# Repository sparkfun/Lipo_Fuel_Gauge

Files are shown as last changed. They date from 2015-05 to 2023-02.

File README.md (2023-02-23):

SparkFun LiPo Fuel Gauge - MAX17043
========================================

SparkFun LiPo Fuel Gauge (https://www.sparkfun.com/products/20680)

[*SparkFun LiPo Fuel Gauge (TOL-20680)*](https://www.sparkfun.com/products/20680)

LiPo batteries are a great way to power your projects. They're small, lightweight, and pack a good punch for their size. Unfortunately, even the best batteries eventually run low on power, and when they do it's often unexpected (and at the worst time). Don't be caught by surprise next time your board suddenly powers down! 

The SparkFun LiPo Fuel Gauge connects your battery to your project and uses a sophisticated algorithm to detect the relative state of charge and direct A/D measurement of battery voltage. In other words, it tells your microcontroller how much 'fuel' is left in the tank. The LiPo Fuel Gauge communicates with your project over I<sup>2</sup>C and an alert pin also tells you when the charge has dropped below a certain percentage.

Repository Contents
-------------------

* **/Firmware** - Example C code 
* **/Hardware** - Eagle design files (.brd, .sch)
* **/Production** - Production panel files (.brd)

Documentation
--------------
* **[Particle Photon Library](https://github.com/sparkfun/SparkFun_MAX17043_Particle_Library)** - Particle Library for the MAX17043 that is used in the [SparkFun Photon Battery Shield](https://www.sparkfun.com/products/13626).
* **[Arduino Project Example](https://learn.sparkfun.com/tutorials/wireless-joystick-hookup-guide#MAX17043)** - Arduino project example that uses the MAX17043 in the [Wireless Joystick Kit](https://www.sparkfun.com/products/14051).
* **[SparkFun Arduino Library](https://github.com/sparkfun/SparkFun_MAX1704x_Fuel_Gauge_Arduino_Library)** - SparkFun Arduino library
* **[Arduino Library](https://github.com/porrey/max1704x)** - Arduino library from user "porrey." This is another Arduino library that is available. 
* **SparkFun Fritzing repo** - Fritzing diagrams for SparkFun products.
  * **[TOL-20680](https://github.com/sparkfun/Fritzing_Parts/blob/main/products/20680_sfe_lipo_fuel_gauge_MAX17043_MAX1704X.fzpz)**
  * **[TOL-10617](https://github.com/sparkfun/Fritzing_Parts/blob/main/products/10617_sfe_lipo_fuel_gauge.fzpz)**
* **[SparkFun 3D Model repo](https://github.com/sparkfun/3D_Models)** - 3D models of SparkFun products.
* **[Hookup Guide](https://learn.sparkfun.com/tutorials/2946)** - Basic hookup guide for the MAX17043 and MAX17048.

Product Versions
----------------
* [TOL-20680](https://www.sparkfun.com/products/20680) - v1.2
* [TOL-10617](https://www.sparkfun.com/products/10617) - Initial Release, v1.1

License Information
-------------------
This product is _**open source**_! 

The **hardware** is released under [Creative Commons ShareAlike 4.0 International](https://creativecommons.org/licenses/by-sa/4.0/).

The **code** is beerware; if you see me (or any other SparkFun employee) at the local, and you've found our code helpful, please buy us a round!

Please use, reuse, and modify these files as you see fit. Please maintain attribution to SparkFun Electronics and release anything derivative under the same license.

Distributed as-is; no warranty is given.

- Your friends at SparkFun.

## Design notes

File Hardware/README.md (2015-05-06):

SparkFun <PRODUCT NAME> Design Files
=====================================

The .sch and .brd files hare are Eagle CAD schematic and PCB design files from SparkFun Electronics.
A freeware version of Eagle can be found [here](http://www.cadsoftusa.com/download-eagle/freeware/). 

License
---------
This product is open source! 
The hardware is released under [Creative Commons ShareAlike 4.0 International](https://creativecommons.org/licenses/by-sa/4.0/).

Please use, reuse, and modify these files as you see fit. Please maintain attribution to SparkFun Electronics and release anything derivative under the same license.

Distributed as-is; no warranty is given.

- Your friends at SparkFun.

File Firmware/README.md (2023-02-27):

SparkFun Lipo Fuel Gauge Firmware
===================================

* **Arduino** - Arduino examples.
* **SparkFunLipoFuelGauge** - C examples. V_1.0

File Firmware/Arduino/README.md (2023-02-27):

SparkFun Lipo Fuel Gauge Firmware
===================================

Documentation
--------------

* **[Installing an Arduino Library Guide](https://learn.sparkfun.com/tutorials/installing-an-arduino-library)** - Basic information on how to install an Arduino library.
* **[SparkFun Qwiic OLED Arduino Library](https://github.com/sparkfun/SparkFun_Qwiic_OLED_Arduino_Library)**
* **[SparkFun MAX1704X Fuel Gauge Arduino Library](https://github.com/sparkfun/SparkFun_MAX1704x_Fuel_Gauge_Arduino_Library)**

_Note: The following examples combine code from both the Qwiic OLED and the LiPo Fuel Gauge Arduino Library. Note that there are two SparkFun Arduino Libraries for the Qwiic Micro OLED that can be used._

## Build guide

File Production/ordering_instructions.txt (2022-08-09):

panel size, 99x211mm
PCB thickness, 1.6mm
number of layers, 2
soldermask color, Red
silkscreen color, White
oz copper, 1oz
finish, HASL lead free
stencils, top
pcs per panel, 64
min trace width, 0.2032mm / 0.0080in
min drill size, 0.3810mm / 0.0150in

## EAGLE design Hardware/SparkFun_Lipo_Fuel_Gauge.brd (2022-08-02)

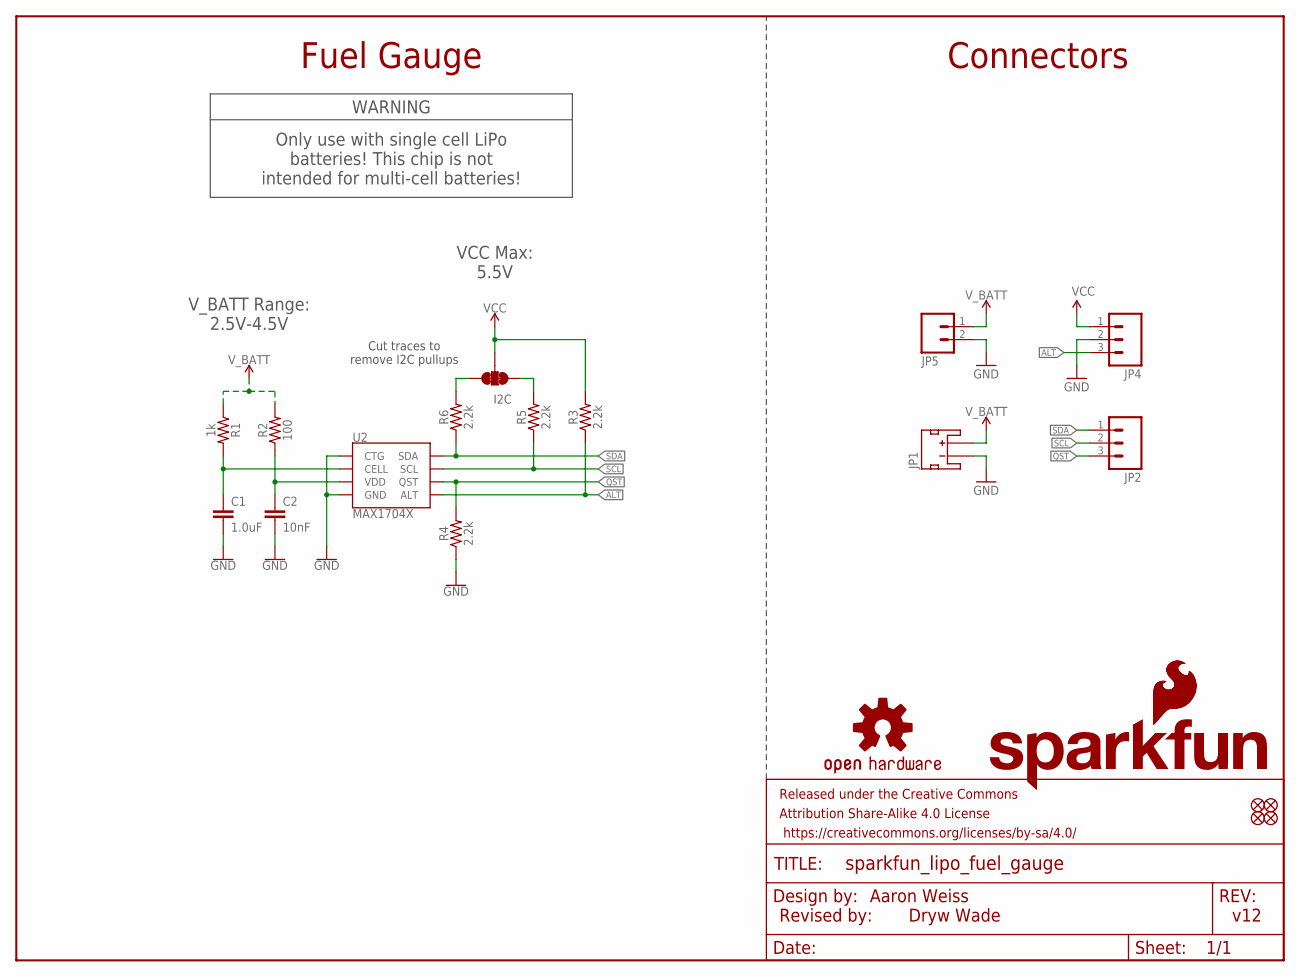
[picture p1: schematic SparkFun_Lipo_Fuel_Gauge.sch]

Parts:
C1: 1.0uF; 0402-TIGHT
C2: 10nF; 0402-TIGHT
FRAME1: FRAME-LETTER; CREATIVE_COMMONS
I2C: JUMPER-SMT_3_2-NC_TRACE_SILK; SMT-JUMPER_3_2-NC_TRACE_SILK
JP1: input; JST-2-SMD
JP2, JP4: CONN_031X03_NO_SILK; 1X03_NO_SILK
JP3: SFE_LOGO_FLAME.1_INCH; SFE_LOGO_FLAME_.1
JP5: CONN_021X02_NO_SILK; 1X02_NO_SILK
JP6, JP7, JP8, JP9: FIDUCIALUFIDUCIAL; FIDUCIAL-MICRO
LOGO1: SFE_LOGO_NAME_FLAMEBLANK; BLANK
R1: 1k; 0402-TIGHT
R2: 100; 0402-TIGHT
R3, R4, R5, R6: 2.2k; 0402-TIGHT
U2: MAX1704X; TDFN-8
U$1: OSHW-LOGOS; OSHW-LOGO-S

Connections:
ALT: JP4.3, R3.1, U2.5 (ALT)
GND: C1.2, C2.2, JP1.1 (-), JP4.2, JP5.2, R4.1, U2.1 (CTG), U2.4 (GND), U2.EP (GND)
unnamed: I2C.3, R6.2
unnamed: C1.1, R1.2, U2.2 (CELL)
unnamed: I2C.1, R5.2
QST: JP2.3, R4.2, U2.6 (QST)
SCL: JP2.2, R5.1, U2.7 (SCL)
SDA: JP2.1, R6.1, U2.8 (SDA)
VCC: I2C.2, JP4.1, R3.2
VDD: C2.1, R2.1, U2.3 (VDD)
V_BATT: JP1.2 (+), JP5.1, R1.1, R2.2

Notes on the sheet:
v12
Aaron Weiss
Revised by:
Dryw Wade
Connectors
Fuel Gauge
WARNING
Only use with single cell LiPo batteries! This chip is not intended for multi-cell batteries!
V_BATT Range: 2.5V-4.5V
VCC Max: 5.5V
Cut traces to remove I2C pullups

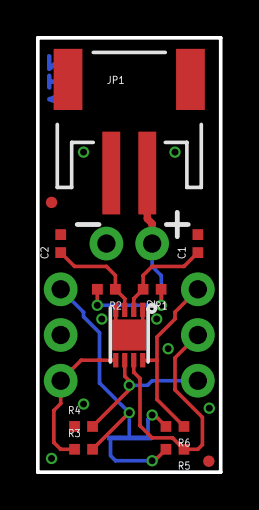
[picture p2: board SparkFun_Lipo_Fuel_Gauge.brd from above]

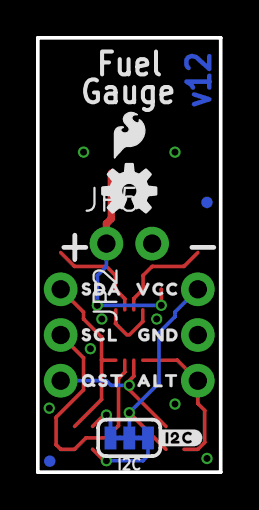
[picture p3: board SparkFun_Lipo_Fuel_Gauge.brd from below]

Board: 2 copper layers, 10.2 x 24.1 mm, 29 parts (15 on the bottom side), 11 nets.

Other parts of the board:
U$2: SDA0
U$3: SCL0
U$4: QST0
U$5: VCC0
U$6: GND0
U$7: ALT0
U$8: #I2C#0

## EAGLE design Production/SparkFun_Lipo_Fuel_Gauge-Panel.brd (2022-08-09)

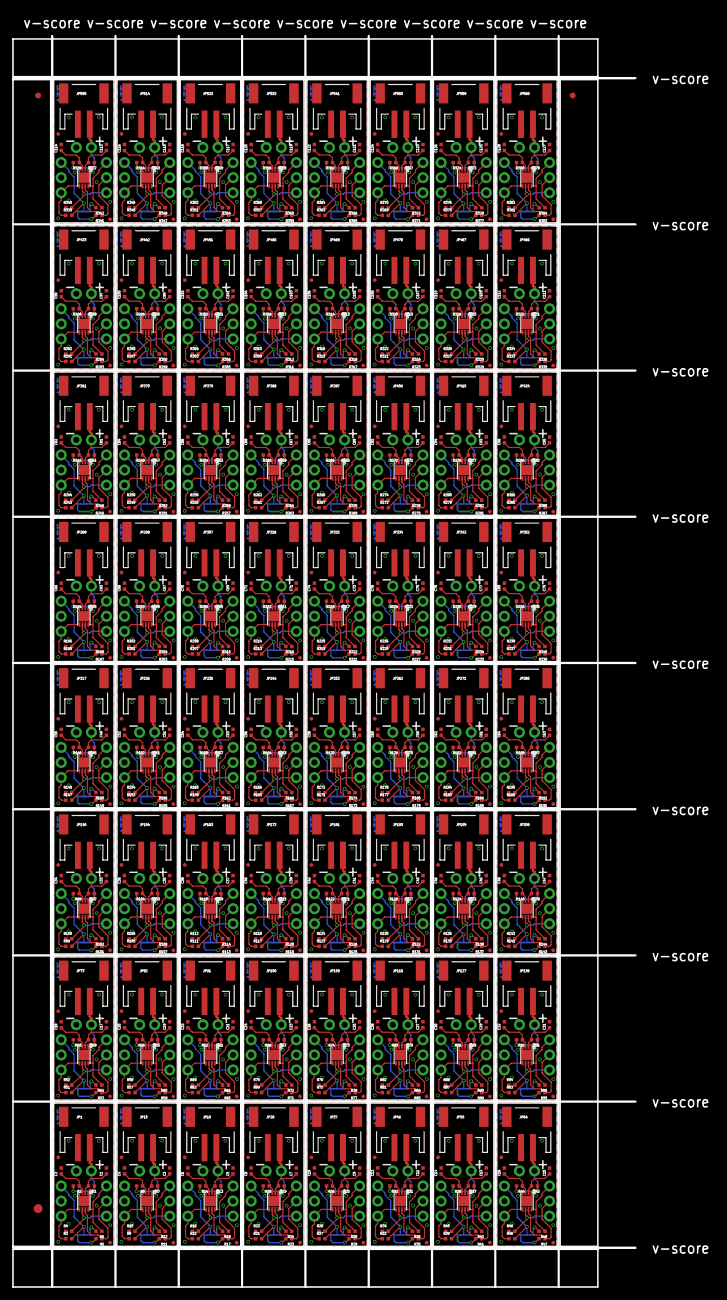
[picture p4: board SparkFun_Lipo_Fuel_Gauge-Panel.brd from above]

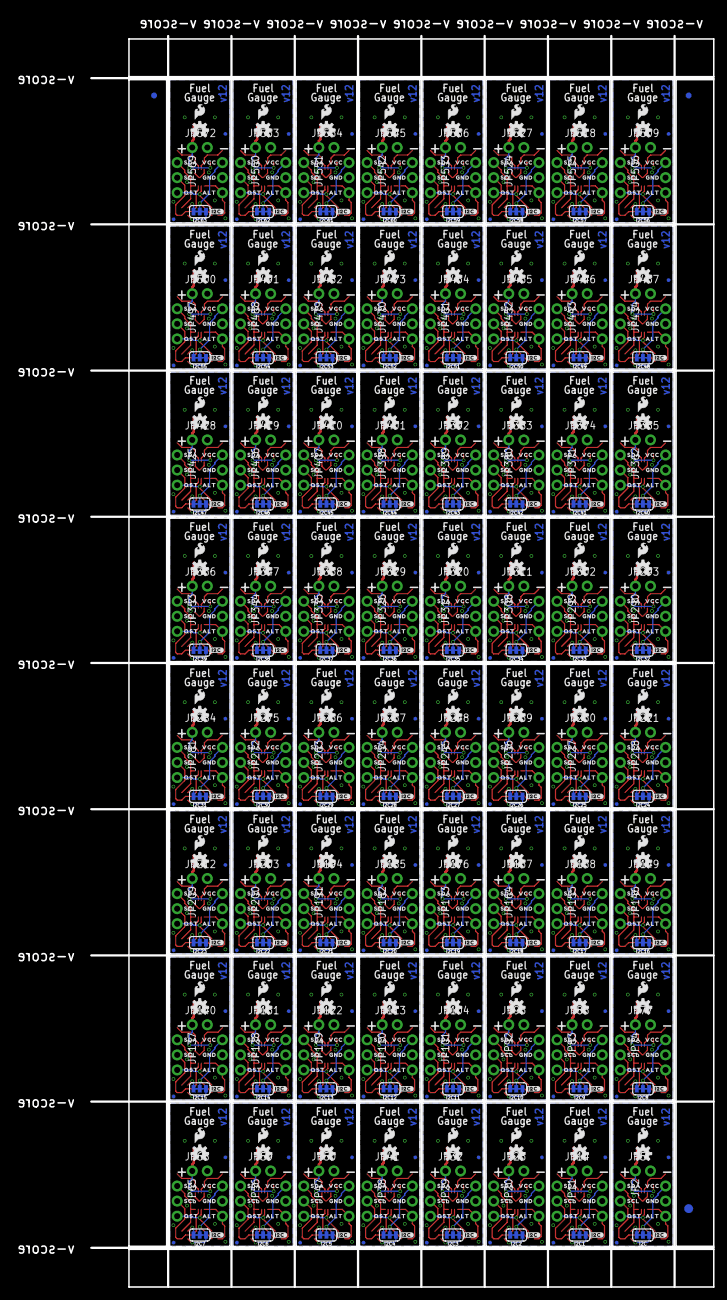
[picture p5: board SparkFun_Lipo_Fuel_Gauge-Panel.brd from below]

Board: 2 copper layers, 104.9 x 210.8 mm, 1798 parts (963 on the bottom side), 704 nets.

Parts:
C1, C3, C5, C7, C9, C11, C13, C15, C17, C19, C21, C23, C25, C27, C29, C31, C33, C35, C37, C39, C41, C43, C45, C47, C49, C51, C53, C55, C57, C59, C61, C63, C65, C67, C69, C71, C73, C75, C77, C79, C81, C83, C85, C87, C89, C91, C93, C95, C97, C99, C101, C103, C105, C107, C109, C111, C113, C115, C117, C119, C121, C123, C125, C127: 1.0uF; 0402-TIGHT
C2, C4, C6, C8, C10, C12, C14, C16, C18, C20, C22, C24, C26, C28, C30, C32, C34, C36, C38, C40, C42, C44, C46, C48, C50, C52, C54, C56, C58, C60, C62, C64, C66, C68, C70, C72, C74, C76, C78, C80, C82, C84, C86, C88, C90, C92, C94, C96, C98, C100, C102, C104, C106, C108, C110, C112, C114, C116, C118, C120, C122, C124, C126, C128: 10nF; 0402-TIGHT
E$1, E$2, E$3, E$4: FIDUCIAL-1X2
E$5, E$6: FIDUCIAL-1.5X3
I2C, I2C1, I2C2, I2C3, I2C4, I2C5, I2C6, I2C7, I2C8, I2C9, I2C10, I2C11, I2C12, I2C13, I2C14, I2C15, I2C16, I2C17, I2C18, I2C19, I2C20, I2C21, I2C22, I2C23, I2C24, I2C25, I2C26, I2C27, I2C28, I2C29, I2C30, I2C31, I2C32, I2C33, I2C34, I2C35, I2C36, I2C37, I2C38, I2C39, I2C40, I2C41, I2C42, I2C43, I2C44, I2C45, I2C46, I2C47, I2C48, I2C49, I2C50, I2C51, I2C52, I2C53, I2C54, I2C55, I2C56, I2C57, I2C58, I2C59, I2C60, I2C61, I2C62, I2C63: JUMPER-SMT_3_2-NC_TRACE_SILK; SMT-JUMPER_3_2-NC_TRACE_SILK
JP1, JP10, JP19, JP28, JP37, JP46, JP55, JP64, JP73, JP82, JP91, JP100, JP109, JP118, JP127, JP136, JP145, JP154, JP163, JP172, JP181, JP190, JP199, JP208, JP217, JP226, JP235, JP244, JP253, JP262, JP271, JP280, JP289, JP298, JP307, JP316, JP325, JP334, JP343, JP352, JP361, JP370, JP379, JP388, JP397, JP406, JP415, JP424, JP433, JP442, JP451, JP460, JP469, JP478, JP487, JP496, JP505, JP514, JP523, JP532, JP541, JP550, JP559, JP568: input; JST-2-SMD
JP2, JP4, JP11, JP12, JP20, JP21, JP29, JP30, JP38, JP39, JP47, JP48, JP56, JP57, JP65, JP66, JP74, JP75, JP83, JP84, JP92, JP93, JP101, JP102, JP110, JP111, JP119, JP120, JP128, JP129, JP137, JP138, JP146, JP147, JP155, JP156, JP164, JP165, JP173, JP174, JP182, JP183, JP191, JP192, JP200, JP201, JP209, JP210, JP218, JP219, JP227, JP228, JP236, JP237, JP245, JP246, JP254, JP255, JP263, JP264, JP272, JP273, JP281, JP282, JP290, JP291, JP299, JP300, JP308, JP309, JP317, JP318, JP326, JP327, JP335, JP336, JP344, JP345, JP353, JP354, JP362, JP363, JP371, JP372, JP380, JP381, JP389, JP390, JP398, JP399, JP407, JP408, JP416, JP417, JP425, JP426, JP434, JP435, JP443, JP444, JP452, JP453, JP461, JP462, JP470, JP471, JP479, JP480, JP488, JP489, JP497, JP498, JP506, JP507, JP515, JP516, JP524, JP525, JP533, JP534, JP542, JP543, JP551, JP552, JP560, JP561, JP569, JP570: 1X03_NO_SILK
JP3, JP13, JP22, JP31, JP40, JP49, JP58, JP67, JP76, JP85, JP94, JP103, JP112, JP121, JP130, JP139, JP148, JP157, JP166, JP175, JP184, JP193, JP202, JP211, JP220, JP229, JP238, JP247, JP256, JP265, JP274, JP283, JP292, JP301, JP310, JP319, JP328, JP337, JP346, JP355, JP364, JP373, JP382, JP391, JP400, JP409, JP418, JP427, JP436, JP445, JP454, JP463, JP472, JP481, JP490, JP499, JP508, JP517, JP526, JP535, JP544, JP553, JP562, JP571: SFE_LOGO_FLAME.1_INCH; SFE_LOGO_FLAME_.1
JP5, JP14, JP23, JP32, JP41, JP50, JP59, JP68, JP77, JP86, JP95, JP104, JP113, JP122, JP131, JP140, JP149, JP158, JP167, JP176, JP185, JP194, JP203, JP212, JP221, JP230, JP239, JP248, JP257, JP266, JP275, JP284, JP293, JP302, JP311, JP320, JP329, JP338, JP347, JP356, JP365, JP374, JP383, JP392, JP401, JP410, JP419, JP428, JP437, JP446, JP455, JP464, JP473, JP482, JP491, JP500, JP509, JP518, JP527, JP536, JP545, JP554, JP563, JP572: 1X02_NO_SILK
JP6, JP7, JP8, JP9, JP15, JP16, JP17, JP18, JP24, JP25, JP26, JP27, JP33, JP34, JP35, JP36, JP42, JP43, JP44, JP45, JP51, JP52, JP53, JP54, JP60, JP61, JP62, JP63, JP69, JP70, JP71, JP72, JP78, JP79, JP80, JP81, JP87, JP88, JP89, JP90, JP96, JP97, JP98, JP99, JP105, JP106, JP107, JP108, JP114, JP115, JP116, JP117, JP123, JP124, JP125, JP126, JP132, JP133, JP134, JP135, JP141, JP142, JP143, JP144, JP150, JP151, JP152, JP153, JP159, JP160, JP161, JP162, JP168, JP169, JP170, JP171, JP177, JP178, JP179, JP180, JP186, JP187, JP188, JP189, JP195, JP196, JP197, JP198, JP204, JP205, JP206, JP207, JP213, JP214, JP215, JP216, JP222, JP223, JP224, JP225, JP231, JP232, JP233, JP234, JP240, JP241, JP242, JP243, JP249, JP250, JP251, JP252, JP258, JP259, JP260, JP261, JP267, JP268, JP269, JP270, JP276, JP277, JP278, JP279, JP285, JP286, JP287, JP288, JP294, JP295, JP296, JP297, JP303, JP304, JP305, JP306, JP312, JP313, JP314, JP315, JP321, JP322, JP323, JP324, JP330, JP331, JP332, JP333, JP339, JP340, JP341, JP342, JP348, JP349, JP350, JP351, JP357, JP358, JP359, JP360, JP366, JP367, JP368, JP369, JP375, JP376, JP377, JP378, JP384, JP385, JP386, JP387, JP393, JP394, JP395, JP396, JP402, JP403, JP404, JP405, JP411, JP412, JP413, JP414, JP420, JP421, JP422, JP423, JP429, JP430, JP431, JP432, JP438, JP439, JP440, JP441, JP447, JP448, JP449, JP450, JP456, JP457, JP458, JP459, JP465, JP466, JP467, JP468, JP474, JP475, JP476, JP477, JP483, JP484, JP485, JP486, JP492, JP493, JP494, JP495, JP501, JP502, JP503, JP504, JP510, JP511, JP512, JP513, JP519, JP520, JP521, JP522, JP528, JP529, JP530, JP531, JP537, JP538, JP539, JP540, JP546, JP547, JP548, JP549, JP555, JP556, JP557, JP558, JP564, JP565, JP566, JP567, JP573, JP574, JP575, JP576: FIDUCIALUFIDUCIAL; FIDUCIAL-MICRO
LOGO1, LOGO2, LOGO3, LOGO4, LOGO5, LOGO6, LOGO7, LOGO8, LOGO9, LOGO10, LOGO11, LOGO12, LOGO13, LOGO14, LOGO15, LOGO16, LOGO17, LOGO18, LOGO19, LOGO20, LOGO21, LOGO22, LOGO23, LOGO24, LOGO25, LOGO26, LOGO27, LOGO28, LOGO29, LOGO30, LOGO31, LOGO32, LOGO33, LOGO34, LOGO35, LOGO36, LOGO37, LOGO38, LOGO39, LOGO40, LOGO41, LOGO42, LOGO43, LOGO44, LOGO45, LOGO46, LOGO47, LOGO48, LOGO49, LOGO50, LOGO51, LOGO52, LOGO53, LOGO54, LOGO55, LOGO56, LOGO57, LOGO58, LOGO59, LOGO60, LOGO61, LOGO62, LOGO63, LOGO64: SFE_LOGO_NAME_FLAMEBLANK; BLANK
R1, R7, R13, R19, R25, R31, R37, R43, R49, R55, R61, R67, R73, R79, R85, R91, R97, R103, R109, R115, R121, R127, R133, R139, R145, R151, R157, R163, R169, R175, R181, R187, R193, R199, R205, R211, R217, R223, R229, R235, R241, R247, R253, R259, R265, R271, R277, R283, R289, R295, R301, R307, R313, R319, R325, R331, R337, R343, R349, R355, R361, R367, R373, R379: 1k; 0402-TIGHT
R2, R8, R14, R20, R26, R32, R38, R44, R50, R56, R62, R68, R74, R80, R86, R92, R98, R104, R110, R116, R122, R128, R134, R140, R146, R152, R158, R164, R170, R176, R182, R188, R194, R200, R206, R212, R218, R224, R230, R236, R242, R248, R254, R260, R266, R272, R278, R284, R290, R296, R302, R308, R314, R320, R326, R332, R338, R344, R350, R356, R362, R368, R374, R380: 100; 0402-TIGHT
R3, R4, R5, R6, R9, R10, R11, R12, R15, R16, R17, R18, R21, R22, R23, R24, R27, R28, R29, R30, R33, R34, R35, R36, R39, R40, R41, R42, R45, R46, R47, R48, R51, R52, R53, R54, R57, R58, R59, R60, R63, R64, R65, R66, R69, R70, R71, R72, R75, R76, R77, R78, R81, R82, R83, R84, R87, R88, R89, R90, R93, R94, R95, R96, R99, R100, R101, R102, R105, R106, R107, R108, R111, R112, R113, R114, R117, R118, R119, R120, R123, R124, R125, R126, R129, R130, R131, R132, R135, R136, R137, R138, R141, R142, R143, R144, R147, R148, R149, R150, R153, R154, R155, R156, R159, R160, R161, R162, R165, R166, R167, R168, R171, R172, R173, R174, R177, R178, R179, R180, R183, R184, R185, R186, R189, R190, R191, R192, R195, R196, R197, R198, R201, R202, R203, R204, R207, R208, R209, R210, R213, R214, R215, R216, R219, R220, R221, R222, R225, R226, R227, R228, R231, R232, R233, R234, R237, R238, R239, R240, R243, R244, R245, R246, R249, R250, R251, R252, R255, R256, R257, R258, R261, R262, R263, R264, R267, R268, R269, R270, R273, R274, R275, R276, R279, R280, R281, R282, R285, R286, R287, R288, R291, R292, R293, R294, R297, R298, R299, R300, R303, R304, R305, R306, R309, R310, R311, R312, R315, R316, R317, R318, R321, R322, R323, R324, R327, R328, R329, R330, R333, R334, R335, R336, R339, R340, R341, R342, R345, R346, R347, R348, R351, R352, R353, R354, R357, R358, R359, R360, R363, R364, R365, R366, R369, R370, R371, R372, R375, R376, R377, R378, R381, R382, R383, R384: 2.2k; 0402-TIGHT
U1, U2, U3, U4, U5, U6, U7, U8, U9, U10, U11, U12, U13, U14, U15, U16, U17, U18, U19, U20, U21, U22, U23, U24, U25, U26, U27, U28, U29, U30, U31, U32, U33, U34, U35, U36, U37, U38, U39, U40, U41, U42, U43, U44, U45, U46, U47, U48, U49, U50, U51, U52, U53, U54, U55, U56, U57, U58, U59, U60, U61, U62, U63, U64: MAX1704X; TDFN-8
U$1, U$9, U$17, U$25, U$33, U$41, U$49, U$57, U$65, U$73, U$81, U$89, U$97, U$105, U$113, U$121, U$129, U$137, U$145, U$153, U$161, U$169, U$177, U$185, U$193, U$201, U$209, U$217, U$225, U$233, U$241, U$249, U$257, U$265, U$273, U$281, U$289, U$297, U$305, U$313, U$321, U$329, U$337, U$345, U$353, U$361, U$369, U$377, U$385, U$393, U$401, U$409, U$417, U$425, U$433, U$441, U$449, U$457, U$465, U$473, U$481, U$489, U$497, U$505: OSHW-LOGOS; OSHW-LOGO-S
U$2, U$11, U$19, U$27, U$35, U$43, U$51, U$59, U$67, U$75, U$83, U$91, U$99, U$107, U$115, U$123, U$131, U$139, U$147, U$155, U$163, U$171, U$179, U$187, U$195, U$203, U$211, U$219, U$227, U$235, U$243, U$251, U$259, U$267, U$275, U$283, U$291, U$299, U$307, U$315, U$323, U$331, U$339, U$347, U$355, U$363, U$371, U$379, U$387, U$395, U$403, U$411, U$419, U$427, U$435, U$443, U$451, U$459, U$467, U$475, U$483, U$491, U$499, U$507: SDA0
U$3, U$12, U$20, U$28, U$36, U$44, U$52, U$60, U$68, U$76, U$84, U$92, U$100, U$108, U$116, U$124, U$132, U$140, U$148, U$156, U$164, U$172, U$180, U$188, U$196, U$204, U$212, U$220, U$228, U$236, U$244, U$252, U$260, U$268, U$276, U$284, U$292, U$300, U$308, U$316, U$324, U$332, U$340, U$348, U$356, U$364, U$372, U$380, U$388, U$396, U$404, U$412, U$420, U$428, U$436, U$444, U$452, U$460, U$468, U$476, U$484, U$492, U$500, U$508: SCL0
U$4, U$13, U$21, U$29, U$37, U$45, U$53, U$61, U$69, U$77, U$85, U$93, U$101, U$109, U$117, U$125, U$133, U$141, U$149, U$157, U$165, U$173, U$181, U$189, U$197, U$205, U$213, U$221, U$229, U$237, U$245, U$253, U$261, U$269, U$277, U$285, U$293, U$301, U$309, U$317, U$325, U$333, U$341, U$349, U$357, U$365, U$373, U$381, U$389, U$397, U$405, U$413, U$421, U$429, U$437, U$445, U$453, U$461, U$469, U$477, U$485, U$493, U$501, U$509: QST0
U$5, U$14, U$22, U$30, U$38, U$46, U$54, U$62, U$70, U$78, U$86, U$94, U$102, U$110, U$118, U$126, U$134, U$142, U$150, U$158, U$166, U$174, U$182, U$190, U$198, U$206, U$214, U$222, U$230, U$238, U$246, U$254, U$262, U$270, U$278, U$286, U$294, U$302, U$310, U$318, U$326, U$334, U$342, U$350, U$358, U$366, U$374, U$382, U$390, U$398, U$406, U$414, U$422, U$430, U$438, U$446, U$454, U$462, U$470, U$478, U$486, U$494, U$502, U$510: VCC0
U$6, U$15, U$23, U$31, U$39, U$47, U$55, U$63, U$71, U$79, U$87, U$95, U$103, U$111, U$119, U$127, U$135, U$143, U$151, U$159, U$167, U$175, U$183, U$191, U$199, U$207, U$215, U$223, U$231, U$239, U$247, U$255, U$263, U$271, U$279, U$287, U$295, U$303, U$311, U$319, U$327, U$335, U$343, U$351, U$359, U$367, U$375, U$383, U$391, U$399, U$407, U$415, U$423, U$431, U$439, U$447, U$455, U$463, U$471, U$479, U$487, U$495, U$503, U$511: GND0
U$7, U$16, U$24, U$32, U$40, U$48, U$56, U$64, U$72, U$80, U$88, U$96, U$104, U$112, U$120, U$128, U$136, U$144, U$152, U$160, U$168, U$176, U$184, U$192, U$200, U$208, U$216, U$224, U$232, U$240, U$248, U$256, U$264, U$272, U$280, U$288, U$296, U$304, U$312, U$320, U$328, U$336, U$344, U$352, U$360, U$368, U$376, U$384, U$392, U$400, U$408, U$416, U$424, U$432, U$440, U$448, U$456, U$464, U$472, U$480, U$488, U$496, U$504, U$512: ALT0
U$8, U$10, U$18, U$26, U$34, U$42, U$50, U$58, U$66, U$74, U$82, U$90, U$98, U$106, U$114, U$122, U$130, U$138, U$146, U$154, U$162, U$170, U$178, U$186, U$194, U$202, U$210, U$218, U$226, U$234, U$242, U$250, U$258, U$266, U$274, U$282, U$290, U$298, U$306, U$314, U$322, U$330, U$338, U$346, U$354, U$362, U$370, U$378, U$386, U$394, U$402, U$410, U$418, U$426, U$434, U$442, U$450, U$458, U$466, U$474, U$482, U$490, U$498, U$506: #I2C#0

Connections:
ALT: JP4.3, R3.1, U2.5
ALT1: JP12.3, R9.1, U1.5
ALT2: JP21.3, R15.1, U3.5
ALT3: JP30.3, R21.1, U4.5
ALT4: JP39.3, R27.1, U5.5
ALT5: JP48.3, R33.1, U6.5
ALT6: JP57.3, R39.1, U7.5
ALT7: JP66.3, R45.1, U8.5
ALT8: JP75.3, R51.1, U9.5
ALT9: JP84.3, R57.1, U10.5
ALT10: JP93.3, R63.1, U11.5
ALT11: JP102.3, R69.1, U12.5
ALT12: JP111.3, R75.1, U13.5
ALT13: JP120.3, R81.1, U14.5
ALT14: JP129.3, R87.1, U15.5
ALT15: JP138.3, R93.1, U16.5
ALT16: JP147.3, R99.1, U17.5
ALT17: JP156.3, R105.1, U18.5
ALT18: JP165.3, R111.1, U19.5
ALT19: JP174.3, R117.1, U20.5
ALT20: JP183.3, R123.1, U21.5
ALT21: JP192.3, R129.1, U22.5
ALT22: JP201.3, R135.1, U23.5
ALT23: JP210.3, R141.1, U24.5
ALT24: JP219.3, R147.1, U25.5
ALT25: JP228.3, R153.1, U26.5
ALT26: JP237.3, R159.1, U27.5
ALT27: JP246.3, R165.1, U28.5
ALT28: JP255.3, R171.1, U29.5
ALT29: JP264.3, R177.1, U30.5
ALT30: JP273.3, R183.1, U31.5
ALT31: JP282.3, R189.1, U32.5
ALT32: JP291.3, R195.1, U33.5
ALT33: JP300.3, R201.1, U34.5
ALT34: JP309.3, R207.1, U35.5
ALT35: JP318.3, R213.1, U36.5
ALT36: JP327.3, R219.1, U37.5
ALT37: JP336.3, R225.1, U38.5
ALT38: JP345.3, R231.1, U39.5
ALT39: JP354.3, R237.1, U40.5
ALT40: JP363.3, R243.1, U41.5
ALT41: JP372.3, R249.1, U42.5
ALT42: JP381.3, R255.1, U43.5
ALT43: JP390.3, R261.1, U44.5
ALT44: JP399.3, R267.1, U45.5
ALT45: JP408.3, R273.1, U46.5
ALT46: JP417.3, R279.1, U47.5
ALT47: JP426.3, R285.1, U48.5
ALT48: JP435.3, R291.1, U49.5
ALT49: JP444.3, R297.1, U50.5
ALT50: JP453.3, R303.1, U51.5
ALT51: JP462.3, R309.1, U52.5
ALT52: JP471.3, R315.1, U53.5
ALT53: JP480.3, R321.1, U54.5
ALT54: JP489.3, R327.1, U55.5
ALT55: JP498.3, R333.1, U56.5
ALT56: JP507.3, R339.1, U57.5
ALT57: JP516.3, R345.1, U58.5
ALT58: JP525.3, R351.1, U59.5
ALT59: JP534.3, R357.1, U60.5
ALT60: JP543.3, R363.1, U61.5
ALT61: JP552.3, R369.1, U62.5
ALT62: JP561.3, R375.1, U63.5
ALT63: JP570.3, R381.1, U64.5
GND: C1.2, C2.2, JP1.1, JP4.2, JP5.2, R4.1, U2.1, U2.4, U2.EP
GND1: C3.2, C4.2, JP10.1, JP12.2, JP14.2, R10.1, U1.1, U1.4, U1.EP
GND2: C5.2, C6.2, JP19.1, JP21.2, JP23.2, R16.1, U3.1, U3.4, U3.EP
GND3: C7.2, C8.2, JP28.1, JP30.2, JP32.2, R22.1, U4.1, U4.4, U4.EP
GND4: C9.2, C10.2, JP37.1, JP39.2, JP41.2, R28.1, U5.1, U5.4, U5.EP
GND5: C11.2, C12.2, JP46.1, JP48.2, JP50.2, R34.1, U6.1, U6.4, U6.EP
GND6: C13.2, C14.2, JP55.1, JP57.2, JP59.2, R40.1, U7.1, U7.4, U7.EP
GND7: C15.2, C16.2, JP64.1, JP66.2, JP68.2, R46.1, U8.1, U8.4, U8.EP
GND8: C17.2, C18.2, JP73.1, JP75.2, JP77.2, R52.1, U9.1, U9.4, U9.EP
GND9: C19.2, C20.2, JP82.1, JP84.2, JP86.2, R58.1, U10.1, U10.4, U10.EP
GND10: C21.2, C22.2, JP91.1, JP93.2, JP95.2, R64.1, U11.1, U11.4, U11.EP
GND11: C23.2, C24.2, JP100.1, JP102.2, JP104.2, R70.1, U12.1, U12.4, U12.EP
GND12: C25.2, C26.2, JP109.1, JP111.2, JP113.2, R76.1, U13.1, U13.4, U13.EP
GND13: C27.2, C28.2, JP118.1, JP120.2, JP122.2, R82.1, U14.1, U14.4, U14.EP
GND14: C29.2, C30.2, JP127.1, JP129.2, JP131.2, R88.1, U15.1, U15.4, U15.EP
GND15: C31.2, C32.2, JP136.1, JP138.2, JP140.2, R94.1, U16.1, U16.4, U16.EP
GND16: C33.2, C34.2, JP145.1, JP147.2, JP149.2, R100.1, U17.1, U17.4, U17.EP
GND17: C35.2, C36.2, JP154.1, JP156.2, JP158.2, R106.1, U18.1, U18.4, U18.EP
GND18: C37.2, C38.2, JP163.1, JP165.2, JP167.2, R112.1, U19.1, U19.4, U19.EP
GND19: C39.2, C40.2, JP172.1, JP174.2, JP176.2, R118.1, U20.1, U20.4, U20.EP
GND20: C41.2, C42.2, JP181.1, JP183.2, JP185.2, R124.1, U21.1, U21.4, U21.EP
GND21: C43.2, C44.2, JP190.1, JP192.2, JP194.2, R130.1, U22.1, U22.4, U22.EP
GND22: C45.2, C46.2, JP199.1, JP201.2, JP203.2, R136.1, U23.1, U23.4, U23.EP
GND23: C47.2, C48.2, JP208.1, JP210.2, JP212.2, R142.1, U24.1, U24.4, U24.EP
GND24: C49.2, C50.2, JP217.1, JP219.2, JP221.2, R148.1, U25.1, U25.4, U25.EP
GND25: C51.2, C52.2, JP226.1, JP228.2, JP230.2, R154.1, U26.1, U26.4, U26.EP
GND26: C53.2, C54.2, JP235.1, JP237.2, JP239.2, R160.1, U27.1, U27.4, U27.EP
GND27: C55.2, C56.2, JP244.1, JP246.2, JP248.2, R166.1, U28.1, U28.4, U28.EP
GND28: C57.2, C58.2, JP253.1, JP255.2, JP257.2, R172.1, U29.1, U29.4, U29.EP
GND29: C59.2, C60.2, JP262.1, JP264.2, JP266.2, R178.1, U30.1, U30.4, U30.EP
GND30: C61.2, C62.2, JP271.1, JP273.2, JP275.2, R184.1, U31.1, U31.4, U31.EP
GND31: C63.2, C64.2, JP280.1, JP282.2, JP284.2, R190.1, U32.1, U32.4, U32.EP
GND32: C65.2, C66.2, JP289.1, JP291.2, JP293.2, R196.1, U33.1, U33.4, U33.EP
GND33: C67.2, C68.2, JP298.1, JP300.2, JP302.2, R202.1, U34.1, U34.4, U34.EP
GND34: C69.2, C70.2, JP307.1, JP309.2, JP311.2, R208.1, U35.1, U35.4, U35.EP
GND35: C71.2, C72.2, JP316.1, JP318.2, JP320.2, R214.1, U36.1, U36.4, U36.EP
GND36: C73.2, C74.2, JP325.1, JP327.2, JP329.2, R220.1, U37.1, U37.4, U37.EP
GND37: C75.2, C76.2, JP334.1, JP336.2, JP338.2, R226.1, U38.1, U38.4, U38.EP
GND38: C77.2, C78.2, JP343.1, JP345.2, JP347.2, R232.1, U39.1, U39.4, U39.EP
GND39: C79.2, C80.2, JP352.1, JP354.2, JP356.2, R238.1, U40.1, U40.4, U40.EP
GND40: C81.2, C82.2, JP361.1, JP363.2, JP365.2, R244.1, U41.1, U41.4, U41.EP
GND41: C83.2, C84.2, JP370.1, JP372.2, JP374.2, R250.1, U42.1, U42.4, U42.EP
GND42: C85.2, C86.2, JP379.1, JP381.2, JP383.2, R256.1, U43.1, U43.4, U43.EP
GND43: C87.2, C88.2, JP388.1, JP390.2, JP392.2, R262.1, U44.1, U44.4, U44.EP
GND44: C89.2, C90.2, JP397.1, JP399.2, JP401.2, R268.1, U45.1, U45.4, U45.EP
GND45: C91.2, C92.2, JP406.1, JP408.2, JP410.2, R274.1, U46.1, U46.4, U46.EP
GND46: C93.2, C94.2, JP415.1, JP417.2, JP419.2, R280.1, U47.1, U47.4, U47.EP
GND47: C95.2, C96.2, JP424.1, JP426.2, JP428.2, R286.1, U48.1, U48.4, U48.EP
GND48: C97.2, C98.2, JP433.1, JP435.2, JP437.2, R292.1, U49.1, U49.4, U49.EP
GND49: C99.2, C100.2, JP442.1, JP444.2, JP446.2, R298.1, U50.1, U50.4, U50.EP
GND50: C101.2, C102.2, JP451.1, JP453.2, JP455.2, R304.1, U51.1, U51.4, U51.EP
GND51: C103.2, C104.2, JP460.1, JP462.2, JP464.2, R310.1, U52.1, U52.4, U52.EP
GND52: C105.2, C106.2, JP469.1, JP471.2, JP473.2, R316.1, U53.1, U53.4, U53.EP
GND53: C107.2, C108.2, JP478.1, JP480.2, JP482.2, R322.1, U54.1, U54.4, U54.EP
GND54: C109.2, C110.2, JP487.1, JP489.2, JP491.2, R328.1, U55.1, U55.4, U55.EP
GND55: C111.2, C112.2, JP496.1, JP498.2, JP500.2, R334.1, U56.1, U56.4, U56.EP
GND56: C113.2, C114.2, JP505.1, JP507.2, JP509.2, R340.1, U57.1, U57.4, U57.EP
GND57: C115.2, C116.2, JP514.1, JP516.2, JP518.2, R346.1, U58.1, U58.4, U58.EP
GND58: C117.2, C118.2, JP523.1, JP525.2, JP527.2, R352.1, U59.1, U59.4, U59.EP
GND59: C119.2, C120.2, JP532.1, JP534.2, JP536.2, R358.1, U60.1, U60.4, U60.EP
GND60: C121.2, C122.2, JP541.1, JP543.2, JP545.2, R364.1, U61.1, U61.4, U61.EP
GND61: C123.2, C124.2, JP550.1, JP552.2, JP554.2, R370.1, U62.1, U62.4, U62.EP
GND62: C125.2, C126.2, JP559.1, JP561.2, JP563.2, R376.1, U63.1, U63.4, U63.EP
GND63: C127.2, C128.2, JP568.1, JP570.2, JP572.2, R382.1, U64.1, U64.4, U64.EP
unnamed: I2C.3, R6.2
unnamed: C1.1, R1.2, U2.2
unnamed: I2C.1, R5.2
unnamed: C3.1, R7.2, U1.2
unnamed: I2C1.3, R12.2
unnamed: I2C1.1, R11.2
unnamed: C5.1, R13.2, U3.2
unnamed: I2C2.3, R18.2
unnamed: I2C2.1, R17.2
unnamed: C7.1, R19.2, U4.2
unnamed: I2C3.3, R24.2
unnamed: I2C3.1, R23.2
unnamed: C9.1, R25.2, U5.2
unnamed: I2C4.3, R30.2
unnamed: I2C4.1, R29.2
unnamed: C11.1, R31.2, U6.2
unnamed: I2C5.3, R36.2
unnamed: I2C5.1, R35.2
unnamed: C13.1, R37.2, U7.2
unnamed: I2C6.3, R42.2
unnamed: I2C6.1, R41.2
unnamed: C15.1, R43.2, U8.2
unnamed: I2C7.3, R48.2
unnamed: I2C7.1, R47.2
unnamed: C17.1, R49.2, U9.2
unnamed: I2C8.3, R54.2
unnamed: I2C8.1, R53.2
unnamed: C19.1, R55.2, U10.2
unnamed: I2C9.3, R60.2
unnamed: I2C9.1, R59.2
unnamed: C21.1, R61.2, U11.2
unnamed: I2C10.3, R66.2
unnamed: I2C10.1, R65.2
unnamed: C23.1, R67.2, U12.2
unnamed: I2C11.3, R72.2
unnamed: I2C11.1, R71.2
unnamed: C25.1, R73.2, U13.2
unnamed: I2C12.3, R78.2
unnamed: I2C12.1, R77.2
unnamed: C27.1, R79.2, U14.2
unnamed: I2C13.3, R84.2
unnamed: I2C13.1, R83.2
unnamed: C29.1, R85.2, U15.2
unnamed: I2C14.3, R90.2
unnamed: I2C14.1, R89.2
unnamed: C31.1, R91.2, U16.2
unnamed: I2C15.3, R96.2
unnamed: I2C15.1, R95.2
unnamed: C33.1, R97.2, U17.2
unnamed: I2C16.3, R102.2
unnamed: I2C16.1, R101.2
unnamed: C35.1, R103.2, U18.2
unnamed: I2C17.3, R108.2
unnamed: I2C17.1, R107.2
unnamed: C37.1, R109.2, U19.2
unnamed: I2C18.3, R114.2
unnamed: I2C18.1, R113.2
unnamed: C39.1, R115.2, U20.2
unnamed: I2C19.3, R120.2
unnamed: I2C19.1, R119.2
unnamed: C41.1, R121.2, U21.2
unnamed: I2C20.3, R126.2
unnamed: I2C20.1, R125.2
unnamed: C43.1, R127.2, U22.2
unnamed: I2C21.3, R132.2
unnamed: I2C21.1, R131.2
unnamed: C45.1, R133.2, U23.2
unnamed: I2C22.3, R138.2
unnamed: I2C22.1, R137.2
unnamed: C47.1, R139.2, U24.2
unnamed: I2C23.3, R144.2
unnamed: I2C23.1, R143.2
unnamed: C49.1, R145.2, U25.2
unnamed: I2C24.3, R150.2
unnamed: I2C24.1, R149.2
unnamed: C51.1, R151.2, U26.2
unnamed: I2C25.3, R156.2
unnamed: I2C25.1, R155.2
unnamed: C53.1, R157.2, U27.2
unnamed: I2C26.3, R162.2
unnamed: I2C26.1, R161.2
unnamed: C55.1, R163.2, U28.2
unnamed: I2C27.3, R168.2
unnamed: I2C27.1, R167.2
unnamed: C57.1, R169.2, U29.2
unnamed: I2C28.3, R174.2
unnamed: I2C28.1, R173.2
unnamed: C59.1, R175.2, U30.2
unnamed: I2C29.3, R180.2
unnamed: I2C29.1, R179.2
unnamed: C61.1, R181.2, U31.2
unnamed: I2C30.3, R186.2
unnamed: I2C30.1, R185.2
unnamed: C63.1, R187.2, U32.2
unnamed: I2C31.3, R192.2
unnamed: I2C31.1, R191.2
unnamed: C65.1, R193.2, U33.2
unnamed: I2C32.3, R198.2
unnamed: I2C32.1, R197.2
unnamed: C67.1, R199.2, U34.2
unnamed: I2C33.3, R204.2
unnamed: I2C33.1, R203.2
unnamed: C69.1, R205.2, U35.2
unnamed: I2C34.3, R210.2
unnamed: I2C34.1, R209.2
unnamed: C71.1, R211.2, U36.2
unnamed: I2C35.3, R216.2
unnamed: I2C35.1, R215.2
unnamed: C73.1, R217.2, U37.2
unnamed: I2C36.3, R222.2
unnamed: I2C36.1, R221.2
unnamed: C75.1, R223.2, U38.2
unnamed: I2C37.3, R228.2
unnamed: I2C37.1, R227.2
unnamed: C77.1, R229.2, U39.2
unnamed: I2C38.3, R234.2
unnamed: I2C38.1, R233.2
unnamed: C79.1, R235.2, U40.2
unnamed: I2C39.3, R240.2
unnamed: I2C39.1, R239.2
unnamed: C81.1, R241.2, U41.2
unnamed: I2C40.3, R246.2
unnamed: I2C40.1, R245.2
unnamed: C83.1, R247.2, U42.2
unnamed: I2C41.3, R252.2
unnamed: I2C41.1, R251.2
unnamed: C85.1, R253.2, U43.2
unnamed: I2C42.3, R258.2
unnamed: I2C42.1, R257.2
unnamed: C87.1, R259.2, U44.2
unnamed: I2C43.3, R264.2
unnamed: I2C43.1, R263.2
unnamed: C89.1, R265.2, U45.2
unnamed: I2C44.3, R270.2
unnamed: I2C44.1, R269.2
unnamed: C91.1, R271.2, U46.2
unnamed: I2C45.3, R276.2
unnamed: I2C45.1, R275.2
unnamed: C93.1, R277.2, U47.2
unnamed: I2C46.3, R282.2
unnamed: I2C46.1, R281.2
unnamed: C95.1, R283.2, U48.2
unnamed: I2C47.3, R288.2
unnamed: I2C47.1, R287.2
unnamed: C97.1, R289.2, U49.2
unnamed: I2C48.3, R294.2
unnamed: I2C48.1, R293.2
unnamed: C99.1, R295.2, U50.2
unnamed: I2C49.3, R300.2
unnamed: I2C49.1, R299.2
unnamed: C101.1, R301.2, U51.2
unnamed: I2C50.3, R306.2
unnamed: I2C50.1, R305.2
unnamed: C103.1, R307.2, U52.2
unnamed: I2C51.3, R312.2
unnamed: I2C51.1, R311.2
unnamed: C105.1, R313.2, U53.2
unnamed: I2C52.3, R318.2
unnamed: I2C52.1, R317.2
unnamed: C107.1, R319.2, U54.2
unnamed: I2C53.3, R324.2
unnamed: I2C53.1, R323.2
unnamed: C109.1, R325.2, U55.2
unnamed: I2C54.3, R330.2
unnamed: I2C54.1, R329.2
unnamed: C111.1, R331.2, U56.2
unnamed: I2C55.3, R336.2
unnamed: I2C55.1, R335.2
unnamed: C113.1, R337.2, U57.2
unnamed: I2C56.3, R342.2
unnamed: I2C56.1, R341.2
unnamed: C115.1, R343.2, U58.2
unnamed: I2C57.3, R348.2
unnamed: I2C57.1, R347.2
unnamed: C117.1, R349.2, U59.2
unnamed: I2C58.3, R354.2
unnamed: I2C58.1, R353.2
unnamed: C119.1, R355.2, U60.2
unnamed: I2C59.3, R360.2
unnamed: I2C59.1, R359.2
unnamed: C121.1, R361.2, U61.2
unnamed: I2C60.3, R366.2
unnamed: I2C60.1, R365.2
unnamed: C123.1, R367.2, U62.2
unnamed: I2C61.3, R372.2
unnamed: I2C61.1, R371.2
unnamed: C125.1, R373.2, U63.2
unnamed: I2C62.3, R378.2
unnamed: I2C62.1, R377.2
unnamed: C127.1, R379.2, U64.2
unnamed: I2C63.3, R384.2
unnamed: I2C63.1, R383.2
QST: JP2.3, R4.2, U2.6
QST1: JP11.3, R10.2, U1.6
QST2: JP20.3, R16.2, U3.6
QST3: JP29.3, R22.2, U4.6
QST4: JP38.3, R28.2, U5.6
QST5: JP47.3, R34.2, U6.6
QST6: JP56.3, R40.2, U7.6
QST7: JP65.3, R46.2, U8.6
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

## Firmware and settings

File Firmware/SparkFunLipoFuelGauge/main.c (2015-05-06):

/*
    6-22-11
	Aaron Weiss
	aaron at sparkfun dot com
	OSHW 1.0 License, http://freedomdefined.org/OSHW
	
	LiPo Fuel Gauge Example Code
	
	Uses the MAX17043
	ATmega328@3.3V w/ external 8MHz resonator
	HF: 0xDA, LF: 0xFF, EF: 0xF8
	
	PIN CONNECTIONS:
	VCC - No connect or connect to system power
	GND - GND
	SDA - PC4
	SCL - PC5
	ALT - PD2
	QST - GND or a hardware reset pin
	
	Default Baud Rate: 9600bps 8N1
	
	Firmware: v10
	Hardware: v10
	
	Usage: Displays the raw A/D value in mV and percentage of 
		   charge every second
	
*/

#include <stdlib.h>
#include <stdio.h>
#include <avr/io.h>
#include <avr/pgmspace.h>
#include <avr/interrupt.h>
#include "types.h"
#include "defs.h"
#include "i2c.h"

#define FOSC 8000000
#define BAUD 9600

#define sbi(var, mask)   ((var) |= (uint8_t)(1 << mask))
#define cbi(var, mask)   ((var) &= (uint8_t)~(1 << mask))

#define STATUS_LED 5

///===========Main Prototypes=============================///////////////////////
void config(void);
void power_on_reset(void);
long read_ad(void);
long read_config(void);
void read_percent(void);
void quick_start_reset(void);

/////=====================================================///////////////////////

///============Initialize Prototypes=====================///////////////////////
void ioinit(void);      // initializes IO
void UART_Init(unsigned int ubrr);
static int uart_putchar(char c, FILE *stream);
uint8_t uart_getchar(void);
static FILE mystdout = FDEV_SETUP_STREAM(uart_putchar, NULL, _FDEV_SETUP_WRITE);
void delay(uint16_t x); // general purpose delay
/////===================================================////////////////////////

///============I2C Prototypes=============//////////////////
void i2cSendStart(void);
void i2cSendStop(void);
void i2cWaitForComplete(void);
void i2cSendByte(unsigned char data);
void i2cInit(void);
void i2cHz(long uP_F, long scl_F);

///===========Global Vars=============================//////////////////////////
volatile long i=0; //counts per second
volatile double percent_decimal;
/////===================================================////////////////////////

//=========MAIN================/////////////////////////////////////////////////
ISR (INT0_vect) 
{	
	//when charge drops below 32% turn on status LED
	sbi(PORTB, STATUS_LED); 
}

ISR(TIMER1_OVF_vect)
{
	//one second timer, prints values every second
	TCNT1 = 34286;
	//printf("config=%5ld, ", read_config());
	printf("a/d=%5ld, ", read_ad());
	read_percent();
	
}

int main(void)
{	
	ioinit(); //Setup IO pins and defaults
	power_on_reset();    // reset MAX module upon MCU reset
	config();
	
	while(1)
	{	
		//put your additional code here
	}
	return (0);
}

void config(void)
{
	/////////write config register///////////////
	
	i2cSendStart();
	i2cWaitForComplete();
	i2cSendByte(0x6C);    //write MAX
	i2cWaitForComplete();
	i2cSendByte(0x0C);    //mode register
	i2cWaitForComplete();
	i2cSendByte(0x97); 
	i2cWaitForComplete();
	i2cSendByte(0x00);    //set alert to 32%
	i2cWaitForComplete();
	i2cSendStop();
	i2cSendStart();	
}

void power_on_reset(void)
{
	/////////write command register to reset///////////////
	
	i2cSendStart();
	i2cWaitForComplete();
	i2cSendByte(0x6C);    //write MAX
	i2cWaitForComplete();
	i2cSendByte(0xFE);    //mode register
	i2cWaitForComplete();
	i2cSendByte(0x54); 
	i2cWaitForComplete();
	i2cSendByte(0x00);    
	i2cWaitForComplete();
	i2cSendStop();
	i2cSendStart();	
}

long read_ad(void)
{		
	//0x6C write, 0x6D read
	
	uint16_t xm, xl;
	long temp, xo;
	
	i2cSendStart();
	i2cWaitForComplete();
	i2cSendByte(0x6C);    //write MAX
	i2cWaitForComplete();
	i2cSendByte(0x02);    //mode register
	i2cWaitForComplete();
	i2cSendStop();
	
	i2cSendStart();
	i2cWaitForComplete();
	i2cSendByte(0x6D);    //read from MAX
	i2cWaitForComplete();
	i2cReceiveByte(TRUE);
	i2cWaitForComplete();
	xm = i2cGetReceivedByte();	//high byte
	i2cWaitForComplete();
	i2cReceiveByte(TRUE);
	i2cWaitForComplete();
	xl = i2cGetReceivedByte();	//high byte
	i2cWaitForComplete();
	i2cReceiveByte(TRUE);	
	i2cSendStop();
	i2cSendStart();
	
	temp = ((xl|(xm << 8)) >> 4);
	xo = 1.25* temp;
	
	//returns A/D value in mV
	return xo;
}

long read_config(void)
{		
	///should read 38656 or 0x9700 before alert
	///should read 38752 or 0x9760 after alert

	//0x6C write, 0x6D read
	
	uint16_t xm, xl;
	long xo;
	
	//////////read command register/////////////
	
	i2cSendStart();
	i2cWaitForComplete();
	i2cSendByte(0x6C);    //write MAX
	i2cWaitForComplete();
	i2cSendByte(0x0C);    //mode register
	i2cWaitForComplete();
	i2cSendStop();
	
	i2cSendStart();
	i2cWaitForComplete();
	i2cSendByte(0x6D);    //read from MAX
	i2cWaitForComplete();
	i2cReceiveByte(TRUE);
	i2cWaitForComplete();
	xm = i2cGetReceivedByte();	//high byte
	i2cWaitForComplete();
	i2cReceiveByte(TRUE);
	i2cWaitForComplete();
	xl = i2cGetReceivedByte();	//high byte
	i2cWaitForComplete();
	i2cReceiveByte(TRUE);	
	i2cSendStop();
	i2cSendStart();	
	
	xo = xl|(xm << 8);
	
	return xo;
}

void read_percent(void)
{		
	//0x6C write, 0x6D read
	
	uint8_t xm, xl;
	//uint8_t xmh, xml, xlh, xll;
	//long xo;
	
	i2cSendStart();
	i2cWaitForComplete();
	i2cSendByte(0x6C);    //write MAX
	i2cWaitForComplete();
	i2cSendByte(0x04);    //SOC register
	i2cWaitForComplete();
	i2cSendStop();
	
	i2cSendStart();
	i2cWaitForComplete();
	i2cSendByte(0x6D);    //read from MAX
	i2cWaitForComplete();
	i2cReceiveByte(TRUE);
	i2cWaitForComplete();
	xm = i2cGetReceivedByte();	//high byte
	i2cWaitForComplete();
	i2cReceiveByte(TRUE);
	i2cWaitForComplete();
	xl = i2cGetReceivedByte();	//high byte
	i2cWaitForComplete();
	i2cReceiveByte(TRUE);	
	i2cSendStop();
	i2cSendStart();
	
	//percent_decimal = (0.003906)*xl + xm;
	//xo = xl|(xm << 8);
	printf("percent=%d\n\r", xm);
	//printf("percent=%4.2f\n\r", percent_decimal);
}

void quick_start_reset(void)
{
	i2cSendStart();
	i2cWaitForComplete();
	i2cSendByte(0x6C);    //write MAX
	i2cWaitForComplete();
	i2cSendByte(0x06);    //mode register
	i2cWaitForComplete();
	i2cSendByte(0x40); 
	i2cWaitForComplete();
	i2cSendByte(0x00);    
	i2cWaitForComplete();
	i2cSendStop();
	i2cSendStart();	
}

////////////////////////////////////////////////////////////////////////////////
///==============Initializations=======================================/////////
////////////////////////////////////////////////////////////////////////////////
void ioinit (void)
{
	//1 = output, 0 = input
	DDRB = 0b11101111; //PB4 = MISO 
	DDRC = 0b11111111; //Output on PORTC0, PORTC4 (SDA), PORTC5 (SCL), all others are inputs
	DDRD = 0b11110010; //PORTD (RX on PD0), input on PD2 ,out on PD5 for ATtiny motor enable

	PORTD |= (1<<PORTD2); //pullup on PD2 
	PORTC = (1<<PORTC4)|(1<<PORTC5); //i2c pullups
	
	cbi(PORTB, STATUS_LED);

	UART_Init((unsigned int)((1000000)/(BAUD*2)-1));
	
	i2cInit();

	//pin change interrupt on INT0
	EICRA = (1<<ISC01);//falling edge generates interrupt
	EIMSK = (1<<INT0);
	
	// Setting Timer 1:
	// normal mode
	TCCR1A = 0x00;
	// Set to clk/256 
	TCCR1B |= (1<<CS12);
	//enable overflow interrupt
	TIMSK1 |= (1<<TOIE1);
	//load timer with a value to optimize for 1 second, 
	//(256/8MHz)*(65536bits-34286) = 1s
	TCNT1 = 34286;
	
	sei(); //turn on global interrupts
}

void UART_Init(unsigned int ubrr)
{
	// Set baud rate 
	UBRR0H = ubrr>>8;
	UBRR0L = ubrr;
	
	// Enable receiver and transmitter 
	UCSR0A = (0<<U2X0);
	UCSR0B = (1<<RXEN0)|(1<<TXEN0);
	
	// Set frame format: 8 bit, no parity, 1 stop bit,   
	UCSR0C = (1<<UCSZ00)|(1<<UCSZ01);
	
	stdout = &mystdout; //Required for printf init
	
	delay(2000);
}

static int uart_putchar(char c, FILE *stream)
{
    if (c == '\n') uart_putchar('\r', stream);
  
    loop_until_bit_is_set(UCSR0A, UDRE0);
    UDR0 = c;
    
    return 0;
}

uint8_t uart_getchar(void)
{
    while( !(UCSR0A & (1<<RXC0)) );
    return(UDR0);
}

//General short delays
void delay(uint16_t x)
{
  uint8_t y;
  for ( ; x > 50 ; x--){
    for ( y = 0 ; y < 200 ; y++){ 
    asm volatile ("nop");
    }
  }
}

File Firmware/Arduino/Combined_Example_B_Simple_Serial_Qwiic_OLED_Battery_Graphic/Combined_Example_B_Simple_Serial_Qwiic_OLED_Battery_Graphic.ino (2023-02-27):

/******************************************************************************
  Combined Simple Serial and Qwiic Micro OLED Example
  Modified By: Ho Yun "Bobby" Chan
  SparkFun Electronics
  Date: February 10, 2023
  License: MIT. See license file for more information but you can
  basically do whatever you want with this code.

  This is a combined example of Paul Clark's MAX17043 Fuel Guage
  simple serial example, Kirk Benell's Qwiic OLED Hello example,
  and Nathan Seidle's RTK Display Test Sketch. The example reads a
  single cell LiPo battery's voltage and state-of-charge (SOC) 
  using the MAX1704X. The voltage, percent remaining (i.e. the 
  SOC), and alert flag are displayed as an output on the Qwiic
  Micro OLED. A graphic of a LiPo battery's remaining charge is
  displayed on the Qwiic Micro OLED as well.

  By opening the Arduino Serial Monitor (115200 baud), the example
  will also print the gauge's voltage, state-of-charge (SOC)
  readings, alert status to Serial.

  Feel like supporting open source hardware?
  Buy a board from SparkFun!

  LiPo Fuel Gauge - MAX17043 : https://www.sparkfun.com/products/20680
  Qwiic Micro OLED: https://www.sparkfun.com/products/14532

  Distributed as-is; no warranty is given.
******************************************************************************/

#include <Wire.h> // Needed for I2C


//////////LIPO FUEL GAUGE//////////
#include <SparkFun_MAX1704x_Fuel_Gauge_Arduino_Library.h> // Click here to get the library: http://librarymanager/All#SparkFun_MAX1704x_Fuel_Gauge_Arduino_Library

SFE_MAX1704X lipo; // Defaults to the MAX17043

//SFE_MAX1704X lipo(MAX1704X_MAX17043); // Create a MAX17043
//SFE_MAX1704X lipo(MAX1704X_MAX17044); // Create a MAX17044
//SFE_MAX1704X lipo(MAX1704X_MAX17048); // Create a MAX17048
//SFE_MAX1704X lipo(MAX1704X_MAX17049); // Create a MAX17049

double voltage = 0; // Variable to keep track of LiPo voltage
double soc = 0; // Variable to keep track of LiPo state-of-charge (SOC)
bool alert; // Variable to keep track of whether alert has been triggered



//////////QWIIC MICRO OLED//////////
#include <SparkFun_Qwiic_OLED.h> //http://librarymanager/All#SparkFun_Qwiic_Graphic_OLED
#include "icons.h"

// The Qwiic OLED Library supports three different types of SparkFun boards. The demo uses the following
// defines to determine which device is being used. Uncomment the device being used for this demo.
QwiicMicroOLED myOLED;
// QwiicTransparentOLED myOLED;
// QwiicNarrowOLED myOLED;

// Fonts
#include <res/qw_fnt_5x7.h>
//#include <res/qw_fnt_8x16.h>, not used
//#include <res/qw_fnt_31x48.h>, not used
//#include <res/qw_fnt_7segment.h>, not used
//#include <res/qw_fnt_largenum.h>, not used



void setup() {
  Serial.begin(115200); // Start serial, to output debug data
  //while (!Serial)
  //  ; //Wait for user to open terminal
  Serial.println(F("Combined MAX17043 Example & Qwiic OLED Example"));

  Wire.begin();

  lipo.enableDebugging(); // Uncomment this line to enable helpful debug messages on Serial

  // Set up the MAX17043 LiPo fuel gauge:
  if (lipo.begin() == false) // Connect to the MAX17043 using the default wire port
  {
    Serial.println(F("MAX17043 not detected. Please check wiring. Freezing."));
    while (1)
      ;
  }

  // Initalize the OLED device and related graphics system
  if (myOLED.begin() == false)
  {
    Serial.println(F("Device begin failed. Freezing..."));
    while (true)
      ;
  }

  // Quick start restarts the MAX17043 in hopes of getting a more accurate
  // guess for the SOC.
  lipo.quickStart();

  // We can set an interrupt to alert when the battery SoC gets too low.
  // We can alert at anywhere between 1% - 32%:
  lipo.setThreshold(20); // Set alert threshold to 20%.
}

void loop() {

  // lipo.getVoltage() returns a voltage value (e.g. 3.93)
  voltage = lipo.getVoltage();

  // lipo.getSOC() returns the estimated state of charge (e.g. 79%)
  soc = lipo.getSOC();

  // lipo.getAlert() clears the alert flag
  // Output: 0 on success, positive integer on fail.
  lipo.clearAlert();
  // lipo.getAlert() returns a 0 or 1 (0=alert not triggered)
  alert = lipo.getAlert();

  myOLED.erase(); //clear display

  //set font type, we'll use a character size of 5x7
  myOLED.setFont(&QW_FONT_5X7);
  //myOLED.setFont(&QW_FONT_8X16); //not used
  //myOLED.setFont(&QW_FONT_31X48); //not used
  //myOLED.setFont(&QW_FONT_LARGENUM); //not used
  //myOLED.setFont(&QW_FONT_7SEGMENT); //not used

  // "Print" Voltage
  myOLED.setCursor(0, 0);
  myOLED.print(voltage, 2);
  myOLED.print(F("V"));

  // "Print" Battery %
  myOLED.setCursor(0, 10);
  myOLED.print(soc, 2);
  myOLED.print(F("%"));

  // "Print" Alert Status
  myOLED.setCursor(0, 20);
  myOLED.print(F("VBAT:")); //alert pin
  if (alert == HIGH) {
    myOLED.print(F("LOW")); //Flag was raised, battery is low!!!
  }
  else {

    myOLED.print(F("OK")); //Battery charge is good. 8)
  }

  if (soc >= 50.00) {
    //Battery Level 50-100%
    displayBitmap(0, 30, Battery_2_Width, Battery_2_Height, Battery_3);
  }
  else if (20.00 <= soc < 50.00) {
    //Battery Level 20-50%
    displayBitmap(0, 30, Battery_2_Width, Battery_2_Height, Battery_2);
  }
  else if (10.00 <= soc < 20.00) {
    //Battery Level 10%-20%
    displayBitmap(0, 30, Battery_2_Width, Battery_2_Height, Battery_1);
  }
  else {
    //Battery Level <10%
    displayBitmap(0, 30, Battery_2_Width, Battery_2_Height, Battery_0);
  }


  // There's nothing on the screen yet - Now send the graphics to the device
  myOLED.display();


  // Print the variables to Serial Terminal:
  Serial.print(F("Voltage: "));
  Serial.print(voltage);  // Print the battery voltage
  Serial.println(" V");

  Serial.print(F("Percentage: "));
  Serial.print(soc); // Print the battery state of charge
  Serial.println(" %");

  Serial.print(F("Alert: "));
  Serial.println(alert);
  Serial.println();

  delay(500);
}



//Wrapper to avoid needing to pass width/height data twice
void displayBitmap(uint8_t x, uint8_t y, uint8_t imageWidth, uint8_t imageHeight, uint8_t *imageData) {
  myOLED.bitmap(x, y, x + imageWidth, y + imageHeight, imageData, imageWidth, imageHeight);
}

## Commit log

2015-05-06 Adding hardware files, readme, example code
    [SparkFun_Lipo_Fuel_Gauge.brd, SparkFun_Lipo_Fuel_Gauge.sch]
2015-10-19 created panel v11
    [SparkFun_Lipo_Fuel_Gauge_Panel_v11.brd]
2022-07-20 Revision updates
    Purpose of revision:
    VCC connects directly to battery, which means a user could connect a 3V3 signal to 4V2 of the battery, causing things to break (see latest 1-star review on product page). This revision is to separate VCC from V_BATT, allowing users to use any voltage for the logic side. Also update to latest standards while we're at it.
    Schematic changes:
    Add Revised By
    Update revision number
    Replace VCC on battery side with V_BATT symbol
    Separate regions of circuit
    Add dashed lines to distinguish circuit regions
    Separate JP1 and JP5
    Replace schematic frame with current version
    Replace "SFE" symbol with SparkFun logo
    Move C2 to connect to VDD directly
    Change flags to ve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
    [SparkFun_Lipo_Fuel_Gauge.brd, SparkFun_Lipo_Fuel_Gauge.sch]
2022-07-21 Design review updates
    Schematic:
    Replace old Eagle devices with current ones
    Update MAX1704X symbol to match current standards
    Add warning about single cell LiPo only
    Add voltage range for V_BATT and VCC
    Add I2C pullup isolation jumper
    Board:
    Fix routing with new footprints
    Route straight out of all pads
    Add vias to increase GND pour
    Switch to Buzzard silk labels
    Add units to measures
    [SparkFun_Lipo_Fuel_Gauge.brd, SparkFun_Lipo_Fuel_Gauge.sch]
2022-07-22 Silk change
    Change Buzzard labels to non-pill style to fit larger text.
    [SparkFun_Lipo_Fuel_Gauge.brd]
2022-07-22 Remove pad numbers from schematic
    [SparkFun_Lipo_Fuel_Gauge.sch]
2022-08-02 Fix MAX1704X PROD_ID
    [SparkFun_Lipo_Fuel_Gauge.brd, SparkFun_Lipo_Fuel_Gauge.sch]
2022-08-09 Update production files for v12
    [SparkFun_Lipo_Fuel_Gauge-Panel.brd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]
2023-02-27 Upload Combined Arduino Examples used in Tutorial

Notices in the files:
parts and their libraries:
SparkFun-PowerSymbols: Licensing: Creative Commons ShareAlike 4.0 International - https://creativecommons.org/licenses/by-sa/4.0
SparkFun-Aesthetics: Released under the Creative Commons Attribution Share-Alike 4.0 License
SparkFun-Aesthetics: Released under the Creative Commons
